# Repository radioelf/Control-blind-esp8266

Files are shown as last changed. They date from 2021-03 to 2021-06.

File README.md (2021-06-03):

# Control-blind-esp8266 (Kicad Version: 5.99.0-unknown nightly)
PCB + software para el control de persianas motorizadas

PCB + software for the control of motorized blinds

Creative Commons License Disclaimer

UNLESS OTHERWISE MUTUALLY AGREED TO BY THE PARTIES IN WRITING, LICENSOR OFFERS THE WORK AS-IS AND MAKES NO REPRESENTATIONS OR WARRANTIES OF ANY KIND CONCERNING THE WORK, EXPRESS, IMPLIED, STATUTORY OR OTHERWISE, INCLUDING, WITHOUT LIMITATION, WARRANTIES OF TITLE, MERCHANTIBILITY, FITNESS FOR A PARTICULAR PURPOSE, NONINFRINGEMENT, OR THE ABSENCE OF LATENT OR OTHER DEFECTS, ACCURACY, OR THE PRESENCE OF ABSENCE OF ERRORS, WHETHER OR NOT DISCOVERABLE. SOME JURISDICTIONS DO NOT ALLOW THE EXCLUSION OF IMPLIED WARRANTIES, SO SUCH EXCLUSION MAY NOT APPLY TO YOU. EXCEPT TO THE EXTENT REQUIRED BY APPLICABLE LAW, IN NO EVENT WILL LICENSOR BE LIABLE TO YOU ON ANY LEGAL THEORY FOR ANY SPECIAL, INCIDENTAL, CONSEQUENTIAL, PUNITIVE OR EXEMPLARY DAMAGES ARISING OUT OF THIS LICENSE OR THE USE OF THE WORK, EVEN IF LICENSOR HAS BEEN ADVISED OF THE POSSIBILITY OF SUCH DAMAGES.

http://creativecommons.org/licenses/by-sa/3.0/

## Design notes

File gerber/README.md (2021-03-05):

Gerber for PCB the control of motorized blinds

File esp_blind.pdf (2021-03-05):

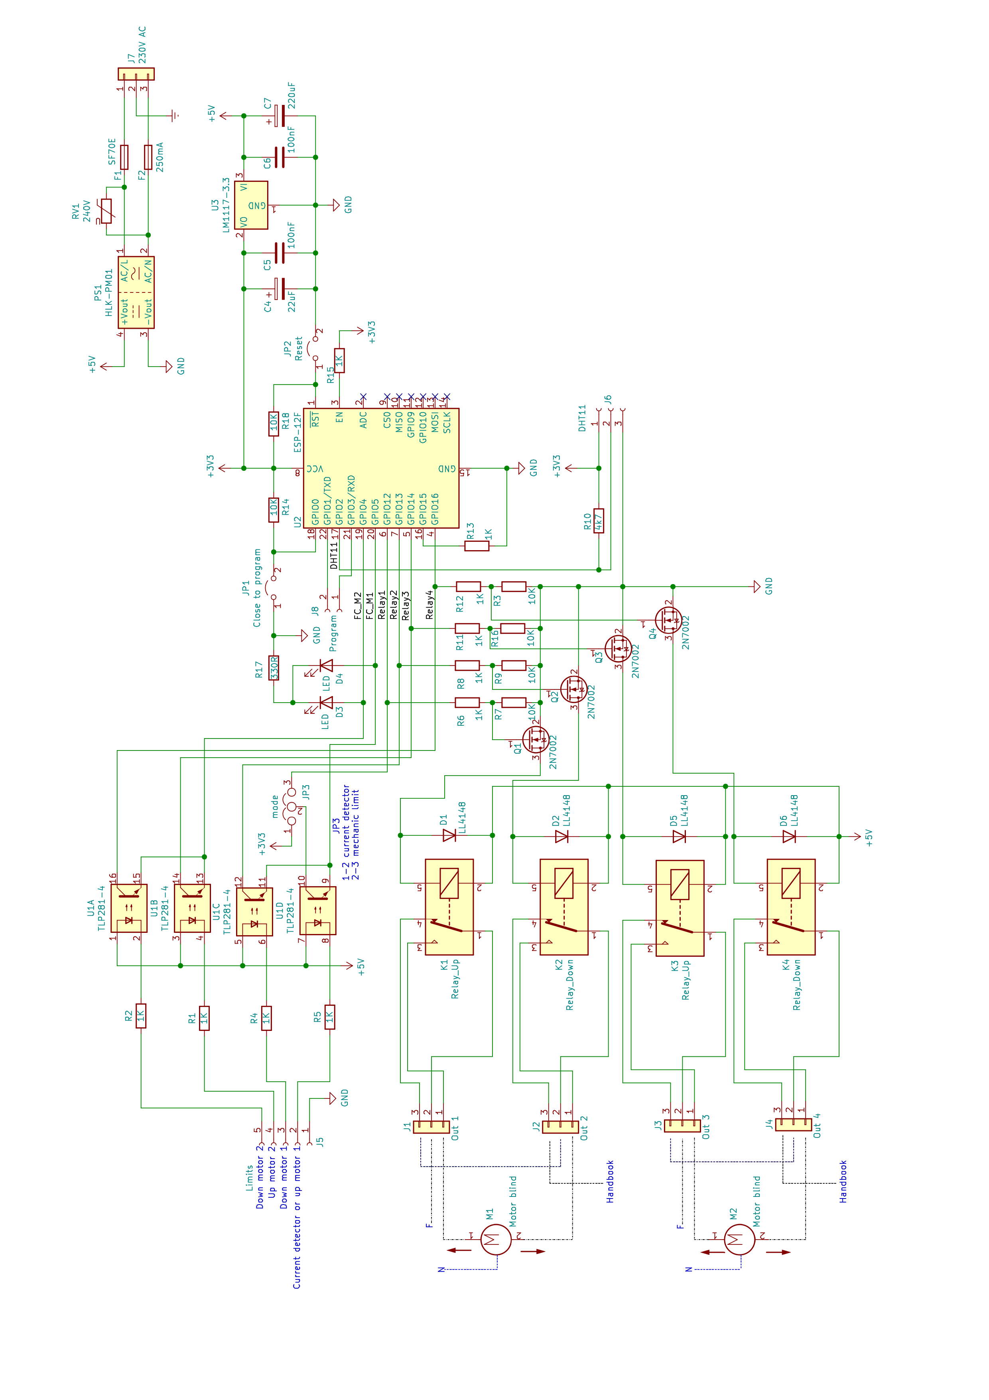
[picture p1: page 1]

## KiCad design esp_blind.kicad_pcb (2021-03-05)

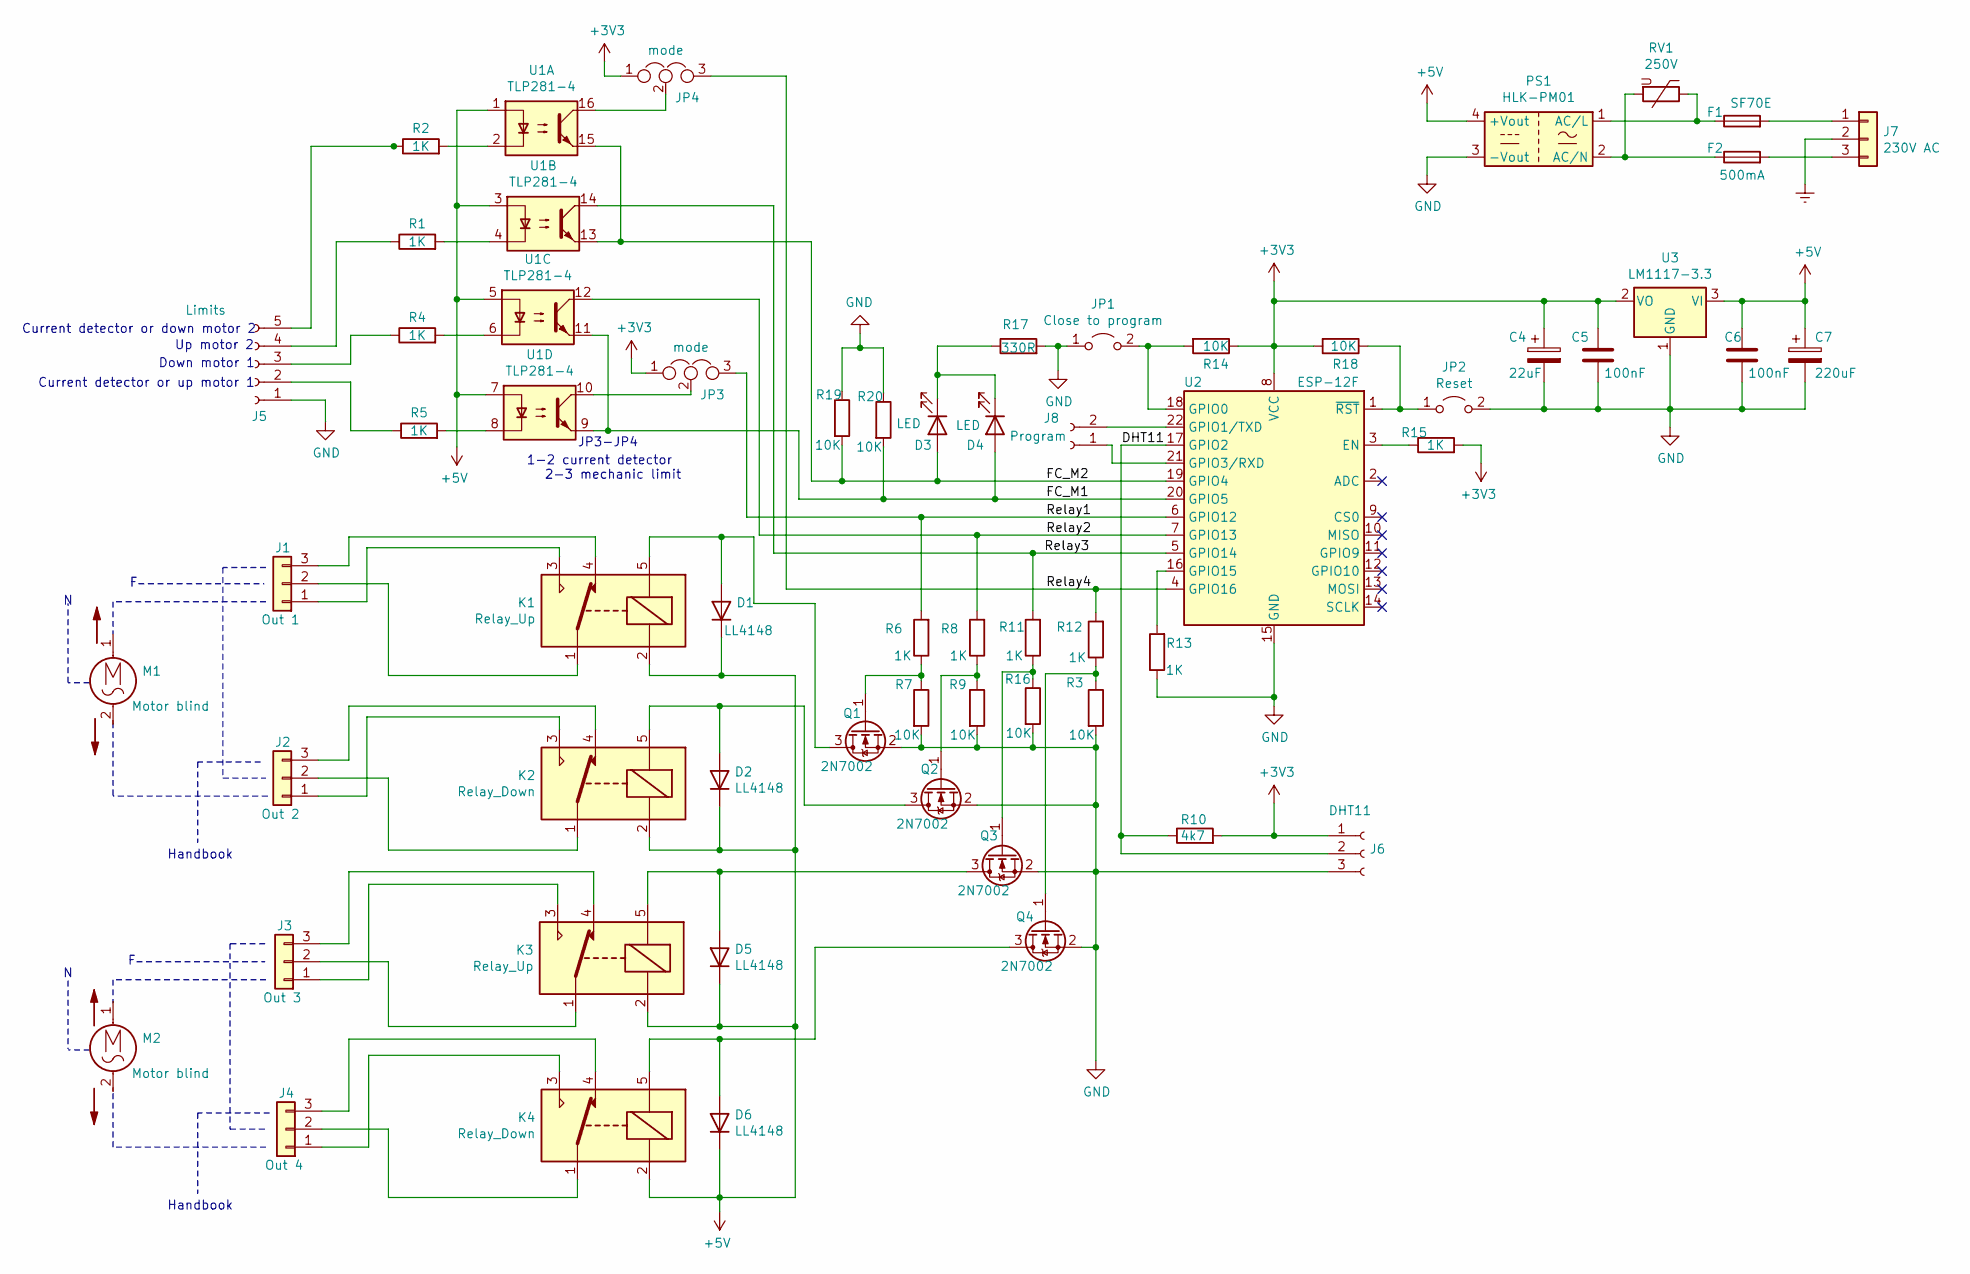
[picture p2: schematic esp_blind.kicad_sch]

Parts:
C4: 22uF; CP_Elec_4x5.8
C5, C6: 100nF; L_0805_2012Metric_Pad1.15x1.40mm_HandSolder
C7: 220uF; CP_Elec_5x4.4
D1, D2, D5, D6: LL4148; D_MiniMELF
D3, D4: LED; LED_0805_2012Metric
F1: SF70E; R_Axial_DIN0411_L9.9mm_D3.6mm_P7.62mm_Vertical
F2: 500mA; R_Axial_DIN0207_L6.3mm_D2.5mm_P7.62mm_Horizontal
J1: Out 1; JST_NV_B03P-NV_1x03_P5.00mm_Vertical
J2: Out 2; JST_NV_B03P-NV_1x03_P5.00mm_Vertical
J3: Out 3; JST_NV_B03P-NV_1x03_P5.00mm_Vertical
J4: Out 4; JST_NV_B03P-NV_1x03_P5.00mm_Vertical
J5: Limits; PinHeader_1x05_P2.54mm_Vertical
J6: DHT11; PinHeader_1x03_P2.54mm_Vertical
J7: 230V AC; JST_NV_B03P-NV_1x03_P5.00mm_Vertical
J8: Program; PinHeader_1x02_P2.54mm_Vertical
JP1: Close to program; PinHeader_1x02_P2.54mm_Vertical
JP2: Reset; PinHeader_1x02_P2.54mm_Vertical
JP3, JP4: mode; SolderJumper-3_P1.3mm_Open_Pad1.0x1.5mm
K1, K3: Relay_Up; Relay_SPDT_SANYOU_SRD_Series_Form_C
K2, K4: Relay_Down; Relay_SPDT_SANYOU_SRD_Series_Form_C
M1, M2: Motor blind
PS1: HLK-PM01; Converter_ACDC_HiLink_HLK-PMxx
Q1, Q2, Q3, Q4: 2N7002; SOT-23
R1, R2, R4, R5, R6, R8, R11, R12, R13, R15: 1K; R_0805_2012Metric
R3, R7, R9, R14, R16, R18, R19, R20: 10K; R_0805_2012Metric
R10: 4k7; R_0805_2012Metric
R17: 330R; R_0805_2012Metric
RV1: 250V; RV_Disc_D12mm_W3.9mm_P7.5mm
U1: TLP281-4; SOIC-16_4.55x10.3mm_P1.27mm
U2: ESP-12F; ESP-12E
U3: LM1117-3.3; SOT-223-3_TabPin2

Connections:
+3V3: C4.1, C5.2, J6.1, JP3.1, JP4.1, R10.2, R14.1, R15.2, R18.2, U2.8 (VCC), U3.2 (VO)
+5V: C6.2, C7.1, D1.1 (K), D2.1 (K), D5.1 (K), D6.1 (K), K1.2, K2.2, K3.2, K4.2, PS1.4 (+Vout), U1.1, U1.3, U1.5, U1.7, U3.3 (VI)
/DHT11: J6.2, R10.1, U2.17 (GPIO2)
/FC_M1: D4.2 (A), R20.2, U1.9, U1.11, U2.20 (GPIO5)
/FC_M2: D3.2 (A), R19.2, U1.13, U1.15, U2.19 (GPIO4)
/Relay1: JP3.3, R6.2, U2.6 (GPIO12)
/Relay2: R8.2, U1.12, U2.7 (GPIO13)
/Relay3: R11.2, U1.14, U2.5 (GPIO14)
/Relay4: JP4.3, R12.2, U2.4 (GPIO16)
Earth: J7.2
GND: C4.2, C5.1, C6.1, C7.2, J5.1, J6.3, JP1.1 (A), JP2.2 (B), PS1.3 (-Vout), Q1.2 (S), Q2.2 (S), Q3.2 (S), Q4.2 (S), R3.2, R7.2, R9.2, R13.1, R16.2, R17.2, R19.1, R20.1, U2.15 (GND), U3.1 (GND)
unnamed: D1.2 (A), K1.5, Q1.3 (D)
unnamed: D2.2 (A), K2.5, Q2.3 (D)
unnamed: D3.1 (K), D4.1 (K), R17.1
unnamed: D5.2 (A), K3.5, Q3.3 (D)
unnamed: D6.2 (A), K4.5, Q4.3 (D)
unnamed: F1.1, PS1.1 (AC/L), RV1.1
unnamed: F1.2, J7.1
unnamed: F2.1, PS1.2 (AC/N), RV1.2
unnamed: F2.2, J7.3
unnamed: J1.1, K1.3
unnamed: J1.2, K1.1
unnamed: J1.3, K1.4
unnamed: J2.1, K2.3
unnamed: J2.2, K2.1
unnamed: J2.3, K2.4
unnamed: J3.1, K3.3
unnamed: J3.2, K3.1
unnamed: J3.3, K3.4
unnamed: J4.1, K4.3
unnamed: J4.2, K4.1
unnamed: J4.3, K4.4
unnamed: J5.2, R5.1
unnamed: J5.3, R4.1
unnamed: J5.4, R1.1
unnamed: J5.5, R2.1
unnamed: J8.1, U2.21 (GPIO3/RXD)
unnamed: J8.2, U2.22 (GPIO1/TXD)
unnamed: JP1.2 (B), R14.2, U2.18 (GPIO0)
unnamed: JP2.1 (A), R18.1, U2.1 (~RST)
unnamed: JP3.2, U1.10
unnamed: JP4.2, U1.16
unnamed: Q1.1 (G), R6.1, R7.1
unnamed: Q2.1 (G), R8.1, R9.1
unnamed: Q3.1 (G), R11.1, R16.1
unnamed: Q4.1 (G), R3.1, R12.1
unnamed: R1.2, U1.4
unnamed: R2.2, U1.2
unnamed: R4.2, U1.6
unnamed: R5.2, U1.8
unnamed: R13.2, U2.16 (GPIO15)
unnamed: R15.1, U2.3 (EN)

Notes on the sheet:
Current detector or down motor 2
Current detector or up motor 1
Down motor 1
Up motor 2
Handbook
JP3-JP4
1-2 current detector
2-3 mechanic limit

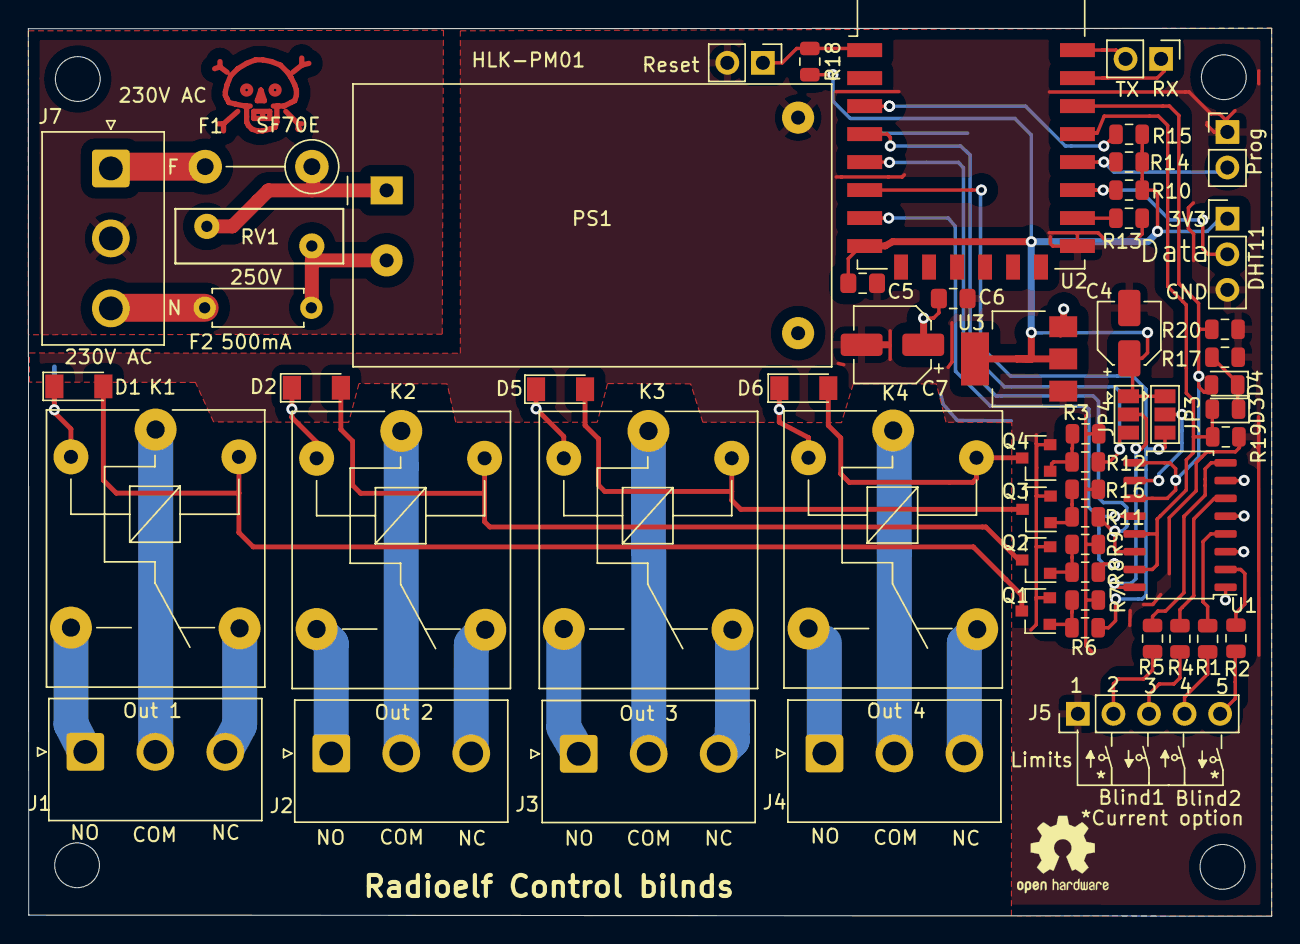
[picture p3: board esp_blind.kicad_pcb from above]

Board: 2 copper layers, 88.8 x 63.4 mm, 58 parts (0 on the bottom side), 51 nets.

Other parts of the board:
230V AC: Danger; Symbol_Danger_CopperTop_Small

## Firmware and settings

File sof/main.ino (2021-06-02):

/*
Control de relés para el control de persianas, y Home Assistant a través de MQTT																		   
 
 Radioelf - mayo 2021
 * 
  http://radioelf.blogspot.com.es/

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
23/5/21 Ver: 0.1.9 

*/
#include <LittleFS.h>
#include <ESP8266WiFi.h>
#include <ESP8266mDNS.h>
#include <ESP8266HTTPClient.h>                                                        // https://github.com/esp8266/Arduino/tree/master/libraries/ESP8266HTTPClient
#include <PubSubClient.h>                                                             // https://github.com/knolleary/pubsubclient/releases/tag/v2.8
#include <Ticker.h>
#include <EEPROM.h>

const uint8_t FC_1 = 5;                                                               // Pin final carrera persiana 1 activado =1, reposo =0
#define FC2 4                                                                         // Pin final carrera persiana 2 activado =1, reposo =0
uint8_t FC_2 = FC2;                                                                   // Puede cambiar
const uint8_t DHTPin = 2;                                                             // Pin data DHT11
const uint8_t Up1Pin = 12;                                                            // Pin subir persiana 1 ON->1, OFF ->0
const uint8_t Down1Pin = 13;                                                          // Pin bajar persiana 1 ON->1, OFF ->0
const uint8_t Up2Pin = 14;                                                            // Pin subir persiana 2 ON->1, OFF ->0
const uint8_t Down2Pin = 16;                                                          // Pin bajar persiana 2 ON->1, OFF ->0

#define DebugSerial 0                                                                 // Debug 

#define NameLocation 3                                                                // Localización persiana

#define AllowHandbook 1                                                               // Permitimos modo automático/manual simultaneo (para pulsadores manuales)

#define DHTsensor 0                                                                   // Soporte para sensor DHT11

#define ForceEEPROM 0                                                                 // Forzamos escribir datos en Eepron

#define mDNS 0                                                                        // Multicast DNS

#define UPTIME_OVERFLOW  4294967295UL                                                 // Uptime overflow

#if AllowHandbook
#warning ATENCION: Se permite el uso simultaneo del control automático y manual (usar pulsadores)
#endif

#define alexaSuport 0                                                                 // Soporte para alexa (NO testeado!!)
#if alexaSuport
#include <fauxmoESP.h>                                                                // https://bitbucket.org/xoseperez/fauxmoesp/get/master.zip
#endif
//************************************************************************************
// En la primera programación el archivo state.txt se debe crear con el contenido "off"
// también se debe de configurar los valores de la EEPRON desde la pagina WEB (modo AP)
// en el segunda programación después de configurar desde web,comentar la siguiente linea
//#define IniConfig
#warning ATENCION Primera programación descomentar #define IniConfig
//************************************************************************************

// Configuración acceso red WiFi
const char *ssid = "ssidxxxxxx";
const char* password = "xxxxxxxx";

//************************************************************************************
// En platformio.ini para usar OTA se debe indicar la misma ip "upload_port = 192.168.0.8x"
//************************************************************************************
#if NameLocation == 1
IPAddress staticIP(192, 168, 1, xx);                                                  // Configuración IP estática taller
String nameLocate = "taller";
uint8_t delayUp1 = 14;                                                                // Tiempo máximo de subida para la persiana 1
uint8_t delayDown1 = 14;                                                              // Tiempo máximo de bajada para la persiana 1
uint8_t delayUp2 = 0;                                                                 // Tiempo máximo de subida para la persiana 2
uint8_t delayDown2 = 0;                                                               // Tiempo máximo de bajada para la persiana 2
#elif NameLocation == 2
IPAddress staticIP(192, 168, 1, xx);                                                  // Configuración IP estática comedor
String nameLocate = "comedor";
uint8_t delayUp1 = 17;                                                                // Tiempo máximo de subida para la persiana 1
uint8_t delayDown1 = 17;                                                              // Tiempo máximo de bajada para la persiana 1
uint8_t delayUp2 = 0;                                                                 // Tiempo máximo de subida para la persiana 2
uint8_t delayDown2 = 0;                                                               // Tiempo máximo de bajada para la persiana 2
#elif NameLocation == 3
IPAddress staticIP(192, 168, 1, xx);                                                  // Configuración IP estática cocina (ESP07)
#warning ATENCION: MODULO ESP07 NO utiliza OTA
String nameLocate = "cocina";
uint8_t delayUp1 = 20;                                                                // Tiempo máximo de subida para la persiana 1
uint8_t delayDown1 = 19;                                                              // Tiempo máximo de bajada para la persiana 1
uint8_t delayUp2 = 0;                                                                 // Tiempo máximo de subida para la persiana 2
uint8_t delayDown2 = 0;                                                               // Tiempo máximo de bajada para la persiana 2
#elif NameLocation == 4
IPAddress staticIP(192, 168, 1, xx);                                                  // Configuración IP estática baño
String nameLocate = "aseo";
uint8_t delayUp1 = 13;                                                                // Tiempo máximo de subida para la persiana 1
uint8_t delayDown1 = 14;                                                              // Tiempo máximo de bajada para la persiana 1
uint8_t delayUp2 = 0;                                                                 // Tiempo máximo de subida para la persiana 2
uint8_t delayDown2 = 0;                                                               // Tiempo máximo de bajada para la persiana 2
#elif NameLocation == 5
IPAddress staticIP(192, 168, 1, xx);                                                  // Configuración IP estática cuartillo
String nameLocate = "cuartillo";
uint8_t delayUp1 = 16;                                                                // Tiempo máximo de subida para la persiana 1
uint8_t delayDown1 = 16;                                                              // Tiempo máximo de bajada para la persiana 1
uint8_t delayUp2 = 0;                                                                 // Tiempo máximo de subida para la persiana 2
uint8_t delayDown2 = 0;                                                               // Tiempo máximo de bajada para la persiana 2
#elif NameLocation == 6
IPAddress staticIP(192, 168, 1, xx);                                                  // Configuración IP estática habitación
#warning ATENCION: MODULO ESP07 NO utiliza OTA
String nameLocate = "habitacion";
uint8_t delayUp1 = 17;                                                                // Tiempo máximo de subida para la persiana 1
uint8_t delayDown1 = 17;                                                              // Tiempo máximo de bajada para la persiana 1
uint8_t delayUp2 = 17;                                                                // Tiempo máximo de subida para la persiana 2
uint8_t delayDown2 = 17;                                                              // Tiempo máximo de bajada para la persiana 2
#elif NameLocation == 7
IPAddress staticIP(192, 168, 1, xx);                                                  // Configuración IP estática pasillo
String nameLocate = "pasillo";
uint8_t delayUp1 = 15;                                                                // Tiempo máximo de subida para la persiana 1
uint8_t delayDown1 = 15;                                                              // Tiempo máximo de bajada para la persiana 1
uint8_t delayUp2 = 15;                                                                // Tiempo máximo de subida para la persiana 2
uint8_t delayDown2 = 15;                                                              // Tiempo máximo de bajada para la persiana 2
#else
IPAddress staticIP(192, 168, 1, xx);                                                  // Configuración IP estática desconocido
String nameLocate = "Desconocido";
uint8_t delayUp1 = 3;                                                                 // Tiempo máximo de subida para la persiana 1
uint8_t delayDown1 = 3;                                                               // Tiempo máximo de bajada para la persiana 1
uint8_t delayUp2 = 0;                                                                 // Tiempo máximo de subida para la persiana 2
uint8_t delayDown2 = 0;                                                               // Tiempo máximo de bajada para la persiana 2
#warning ATENCION No tenemos una localización valida
#endif

IPAddress gateway(192, 168, 0, xx);
IPAddress dnServer(192, 168, 0, xx);
IPAddress subnet(255, 255, 255, 0);

// MQTT
const char* MQTT_SERVER = "192.168.0.xxx";                                            // Dirección IP del servidor MQTT
const uint16_t MQTT_PORT = 1883;                                                      // MQTT puerto broker
const char* userMQTT = "xxxxxxxx";
const char* passMQTT = "xxxxxxxx";

String clientId = "_blind";
bool MQTT_RETAIN = false;                                                             // MQTT bandera retain (retención)
uint8_t MQTT_QOS = 0;                                                                 // MQTT QoS mensajes
const char* willTopic = 0;                                                            // MQTT willTopic
const char* willMessage = 0;                                                          // MQTT willMessage

// Temporizador
unsigned long ultimaConsulta = 0;
unsigned long tiempoConsulta = 270000;                                                // 4.5 minutos (<MQTT_KEEPALIVE)
unsigned long periodRun1;                                                             // Periodo de marcha persiana 1
unsigned long periodRun2;                                                             // Periodo de marcha persiana 2
unsigned long fcRun1;                                                                 // Periodo activo final de carrera para persiana 1
unsigned long fcRun2;                                                                 // Periodo activo final de carrera para persiana 2

unsigned long periodFcI1;                                                             // Periodo conmutación on-off final carrera por intensidad persiana 1
unsigned long periodFcI2;                                                             // Periodo conmutación on-off final carrera por intensidad persiana 2
uint16_t OnOffI_FC = 250;                                                             // Periodo de paso a off del final carrera por intensidad

uint8_t ReleFalg = 0b00000000;                                                        // Banderas estado relés
uint16_t webFalg = 0b0000000000100000;                                                // Banderas de opciones pagina web
uint8_t updateWeb = 0;                                                                // Indicación actualizar opciones web
volatile uint8_t statusFC = 0;                                                        // Banderas indicación estado de los finales de carrera
uint8_t runBlind = 0;                                                                 // Banderas estado marcha persianas
uint8_t position1 = 50;                                                               // Posición actual persiana 1, Abierta =100%, Cerrada =0% 
uint8_t position2 = 50;                                                               // Posición actual persiana 2, Abierta =100%, Cerrada =0% 
uint8_t setPosition1 = position1;
uint8_t setPosition2 = position2;
uint8_t autoDetec = 0;                                                                // Auto detección posición persianas al iniciar
uint8_t error = 0;                                                                    // Indicación del tipo de error
volatile bool iniRunFc1 = false;                                                      // inicializado F.C persiana 1, 0 -> no , 1 -> inicializado
volatile bool iniRunFc2 = false;                                                      // inicializado F.C persiana 2, 0 -> no , 1 -> inicializado
bool activeBlind1 = true;                                                             // persiana 1 activa (editable desde web en modo AP)
bool activeBlind2 = false;                                                            // persiana 2 NO activa (editable desde web en modo AP)
volatile bool StopIsr1 = false;                                                       // bandera ISR timer 1
volatile bool StopIsr2 = false;                                                       // bandera ISR timer 2
bool CommandSTOP1 = false;                                                            // STOP persiana 1 desde MQTT
bool CommandSTOP2 = false;                                                            // STOP persiana 2 desde MQTT

bool Fs = false;
bool modeHandbook = false;                                                            // mode->false modo automático habilitado

uint8_t modeLimit = 2;                                                                // F.C 0-> NO usado, 1-> físicos, 2-> corriente
bool okMqtt = false;
uint8_t locate = 0;
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
void loop() {
  if (APmode) {                                                                       // SIN conexión WIFI, modo Punto de Acceso?
    webReturn = connectAP();                                                          // SI, RUN Punto de Acceso + web
    if (updateWeb) webUpdate();                                                       // Datos a actualizar desde web en modo AP
    delay(1);
    if (++cicleDisConnec == delayAP) {
      if (delayAP > 60000) espReset();                                                // Modo AP forzado por comando "apmodeCmd"
      cicleDisConnec = 0;
      if (listNetworks(ssid))
        reConnect();                                                                  // Cada minuto en modo AP se re-intenta conectar
    }
#ifdef IniConfig
    cicleDisConnec = 0;
#endif
  }
  else {
#if alexaSuport
    if (alexaRun) alexa.handle();
#endif
    if (!client.connected() || WiFi.status() != 3) {                                  // Reconectar si se perdió la conexión wifi o mqtt
      reConnect();                                                                    // Re-intenta conectar
    }
    if ((millis() - ultimaConsulta) > tiempoConsulta) {                               // Gestión temporizador periódico 4.5 minutos
      if (++cicleConnec == (39 + NameLocation)) {                                     // 4.5 * 40 = 180 minutos
        cicleConnec = 0;
        locate = 0;                                                                   // Reenviamos Auto descubrimiento Home Assistant
      }
#if DHTsensor
      OkDht = ReadDHT();                                                              // Leemos sensor DHT11
#endif
      publicMqtt();                                                                   // Publicación MQTT periódica
      ultimaConsulta = millis();
    }
    client.loop();                                                                    // Mantenemos activa la conexión MQTT
    ArduinoOTA.handle();
  }

#if DebugSerial
  if (runBlind == 0) {                                                                // Persianas en reposo?
    if (millis() % 5000 == 0) {                                                       // Info...
    debugPrintln(String(F("En marcha: ")) + uptime_formatter::getUptime());
    debugPrintln(String(F("Persiana: ")) + String(nameLocate)); // Nombre
    debugPrintln(String(F("ID: ")) + clientId);                 // ID
    if (iniRunFc1 == false)
      debugPrintln(F("Posición persiana 1 desconocida"));
    else
      debugPrintln(String(F("Posición persiana 1: ")) + String(position1));
    if (iniRunFc2 == false && activeBlind2)
      debugPrintln(F("Posición persiana 2 desconocida"));
    else
      debugPrintln(String(F("Posición persiana 2: ")) + String(position2));
    if (WiFi.status() == WL_CONNECTED)
    {                                                          // Conectado a WIFI?
      debugPrintln(String(F("Conectado a: ")) + String(ssid)); // SSID
      debugPrintln(String(F("WIFI: RSSI: ")) + WiFi.RSSI());   // Nivel señal wifi
      if (client.connected())
      { // Conectado a MQTT?
        debugPrintln(F("Conectado a MQTT"));
      }
      else
      {
        debugPrintln(F("NO Conectado a MQTT"));
      }
      }
      else {
        debugPrintln(F("!!DESCONECTADO!!"));
      } 
    }
  }
#endif

  if (bitRead (ReleFalg, 7)) RelayStatus();                                           // Comprobamos si tenemos activo algún relé
  if (modeLimit) LimitsActive (LimitStatus());                                        // Comprobamos si usamos finales de carrera

#if alexaSuport
  if (bitRead (alexaFalg, 7)) RelayStatus();                                          // Gestión actualización cambio estado relés por Alexa
#endif  
}

//************************************************************************************
// Gestionamos ordenes y configuración enviados desde la pagina web en modo punto de acceso
//************************************************************************************
void webUpdate() {
  uint8_t x;
  bool eppronWire = 0;
  cicleConnec = 0;
  if (updateWeb == 2) {                                                               // Configuración
    EEPROM.begin(100);
#if DebugSerial
    debugPrintln(F("Configuración WEB"));
#endif
    updateWeb = 0;
    if (bitRead(webFalg, 5)) {                                                        // Persiana 1 activa?
      activeBlind1 = 1;
      x = EEPROM.read(5);
      if (x != activeBlind1) {
        EEPROM.write (5, activeBlind1);
        eppronWire = 1;
      }
#if DebugSerial
      debugPrintln(F("Control persiana 1 habilitado"));
#endif
    }
    else {                                                                            // Persiana 1 NO activa
      activeBlind1 = 0;
      x = EEPROM.read(5);
      if (x != activeBlind1) {                                                        // SOLO escribimos si el valor de la EEPROM es distinto
        EEPROM.write (5, activeBlind1);
        eppronWire = 1;
      }
#if DebugSerial
      debugPrintln(F("Control persiana 1 deshabilitado"));
#endif
    }
    if (bitRead(webFalg, 6)) {                                                        // Persiana 2 activa?
      activeBlind2 = 1;
      x = EEPROM.read(6);
      if (x != activeBlind2) {                                                        // SOLO escribimos si el valor de la EEPROM es distinto
        EEPROM.write (6, activeBlind2);
        eppronWire = 1;
      }
#if DebugSerial
      debugPrintln(F("Control persiana 2 habilitado"));
#endif
    }
    else {
      activeBlind2 = 0;                                                               // Persiana 2 NO activa
      x = EEPROM.read(6);
      if (x != activeBlind2) {                                                        // SOLO escribimos si el valor de la EEPROM es distinto
        EEPROM.write (6, activeBlind2);
        eppronWire = 1;
      }
#if DebugSerial
      debugPrintln(F("Control persiana 2 deshabilitado"));
#endif
    }
    if (bitRead(webFalg, 7)) {                                                        // Tipo de F.C ->por consumo
      modeLimit = 2;
      x = EEPROM.read(7);
      if (x != modeLimit) {
        EEPROM.write (7, modeLimit);
        eppronWire = 1;
      }
#if DebugSerial
      debugPrintln(F("Finales de carrera por control consumo motor"));
#endif
    }
    if (bitRead(webFalg, 8)) {                                                        // Tipo de F.C -> físicos
      modeLimit = 1;
      x = EEPROM.read(7);
      if (x != modeLimit) {
        EEPROM.write (7, modeLimit);
        eppronWire = 1;
      }
#if DebugSerial
      debugPrintln(F("Finales de carrera físicos"));
#endif
    }
    if (bitRead(webFalg, 9)) {                                                        // Tipo de F.C ->NO usados
      modeLimit = 0;
      bitClear(webFalg, 9);
      x = EEPROM.read(7);
      if (x != modeLimit) {
        EEPROM.write (7, modeLimit);
        eppronWire = 1;
      }
#if DebugSerial
      debugPrintln(F("NO usamos finales carrera"));
#endif
    }
    if (autoDetec != bitRead(webFalg, 10)) {                                          // Auto detención posición persiana al inicio?
      autoDetec = bitRead(webFalg, 10);
      bitClear(webFalg, 10);
      x = EEPROM.read(8);
      if (x != autoDetec) {
        EEPROM.write (8, autoDetec);
        eppronWire = 1;
      }
#if DebugSerial
      debugPrintln(String(F("Auto-detección posición persianas ")) + autoDetec ? "habilitado" : "deshabilitado");
#endif
    }

    if (alexaRun != bitRead(webFalg, 11)) {                                           // Config. alexa?
      alexaRun = bitRead(webFalg, 11);
      x = EEPROM.read(9);
      if (x != alexaRun) {
        EEPROM.write (9, alexaRun);
        eppronWire = 1;
      }
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

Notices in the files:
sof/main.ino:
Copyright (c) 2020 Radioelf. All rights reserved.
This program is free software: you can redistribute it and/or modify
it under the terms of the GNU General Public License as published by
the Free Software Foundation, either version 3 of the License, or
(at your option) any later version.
